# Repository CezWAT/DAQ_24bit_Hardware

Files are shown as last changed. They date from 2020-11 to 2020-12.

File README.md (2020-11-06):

# DAQ_24bit
Simple 4 channel 24bit USB DAQ
Uses ADS122U04 ADC and MCP2200 UART/GPIO - USB converter. No Dedicated uC.
4 Input channels with 4 ranges (+- 1V, 2V, 10V, 25V) and 2 current output channels.

Project for fun and curiosity with a purpose to make a simple yte precise USB DAQ without a dedicated controller requireig firmware. 

Forked to add an Eagle based pcb made by myself.

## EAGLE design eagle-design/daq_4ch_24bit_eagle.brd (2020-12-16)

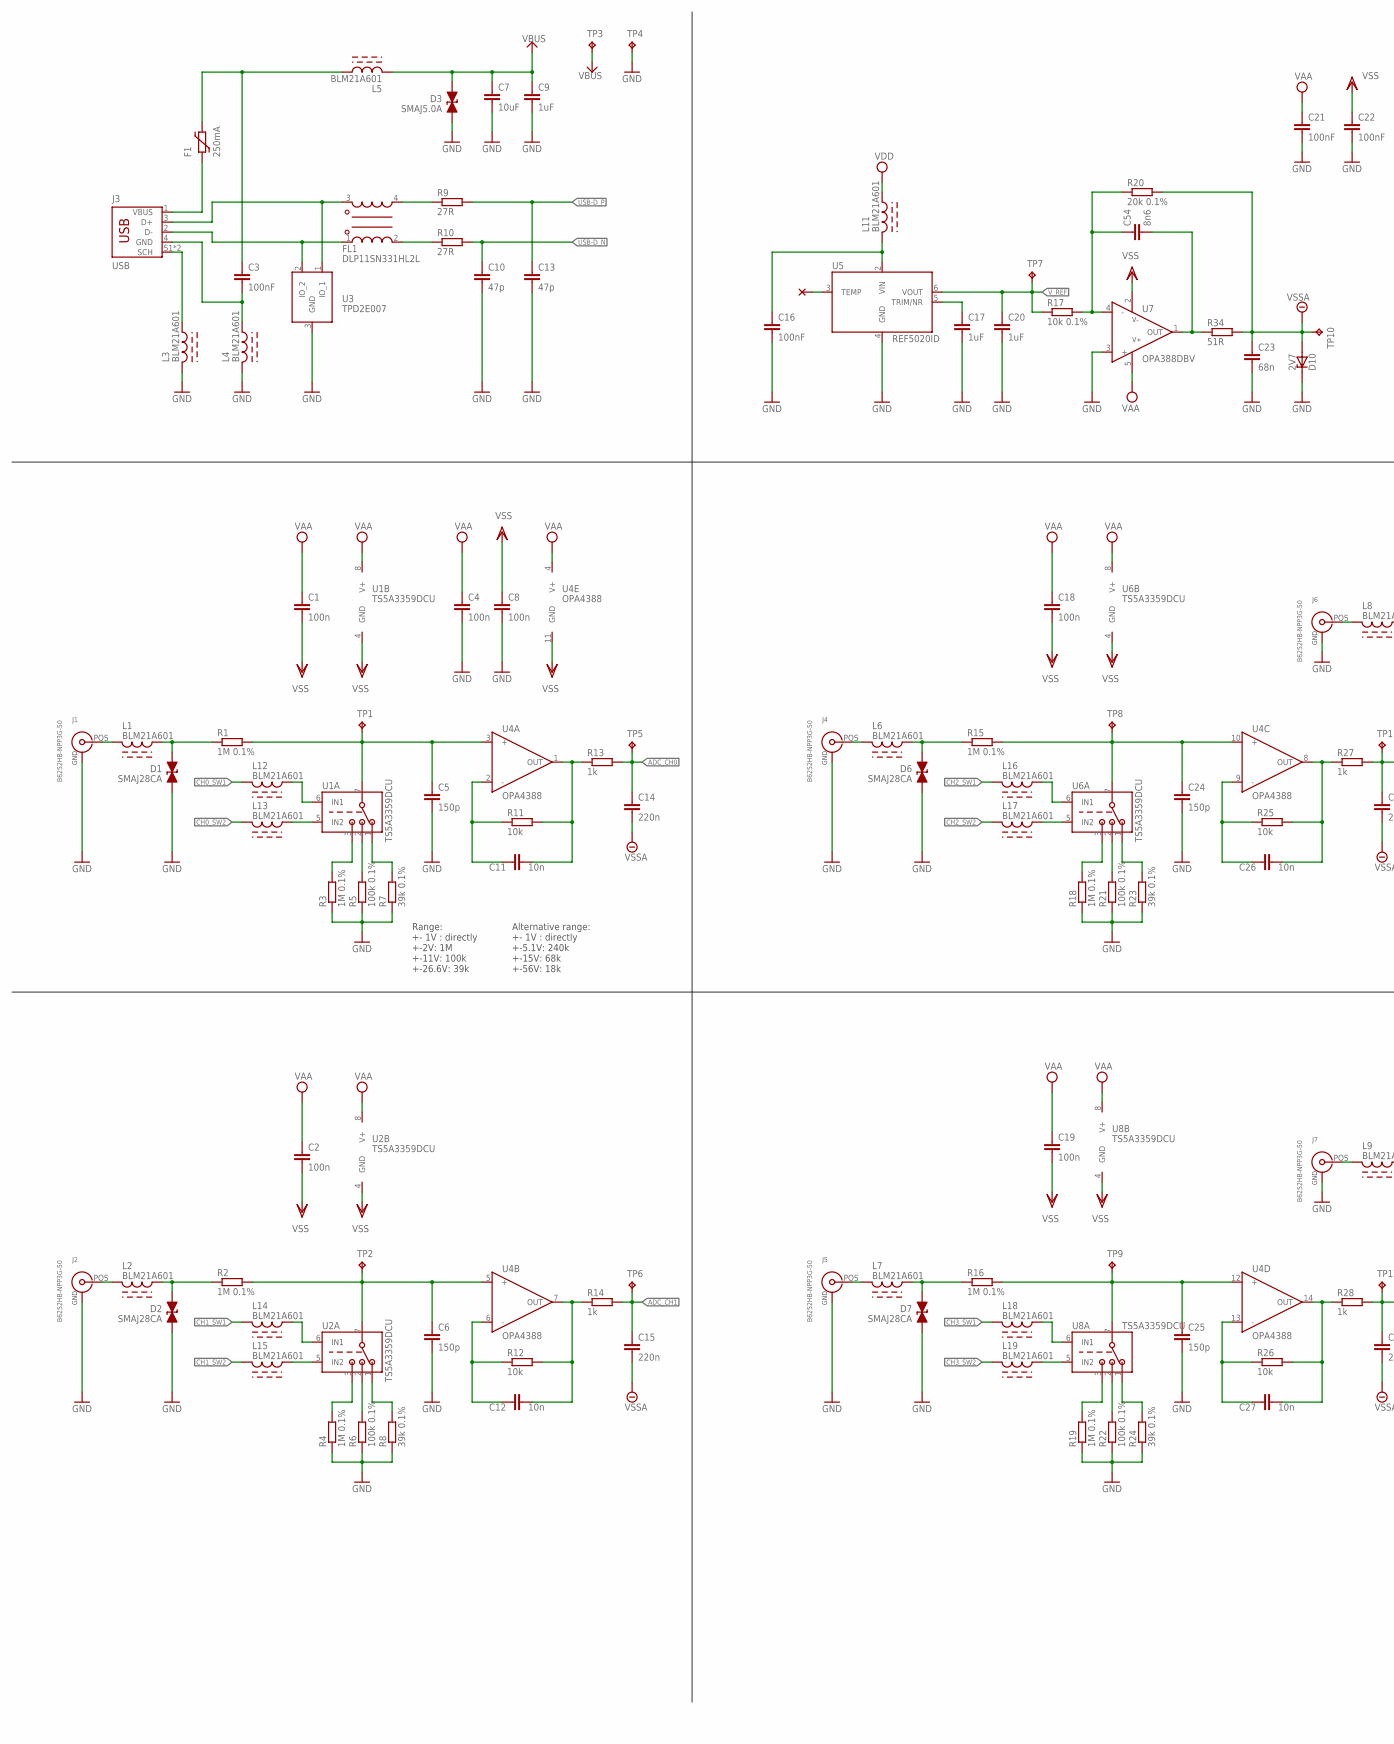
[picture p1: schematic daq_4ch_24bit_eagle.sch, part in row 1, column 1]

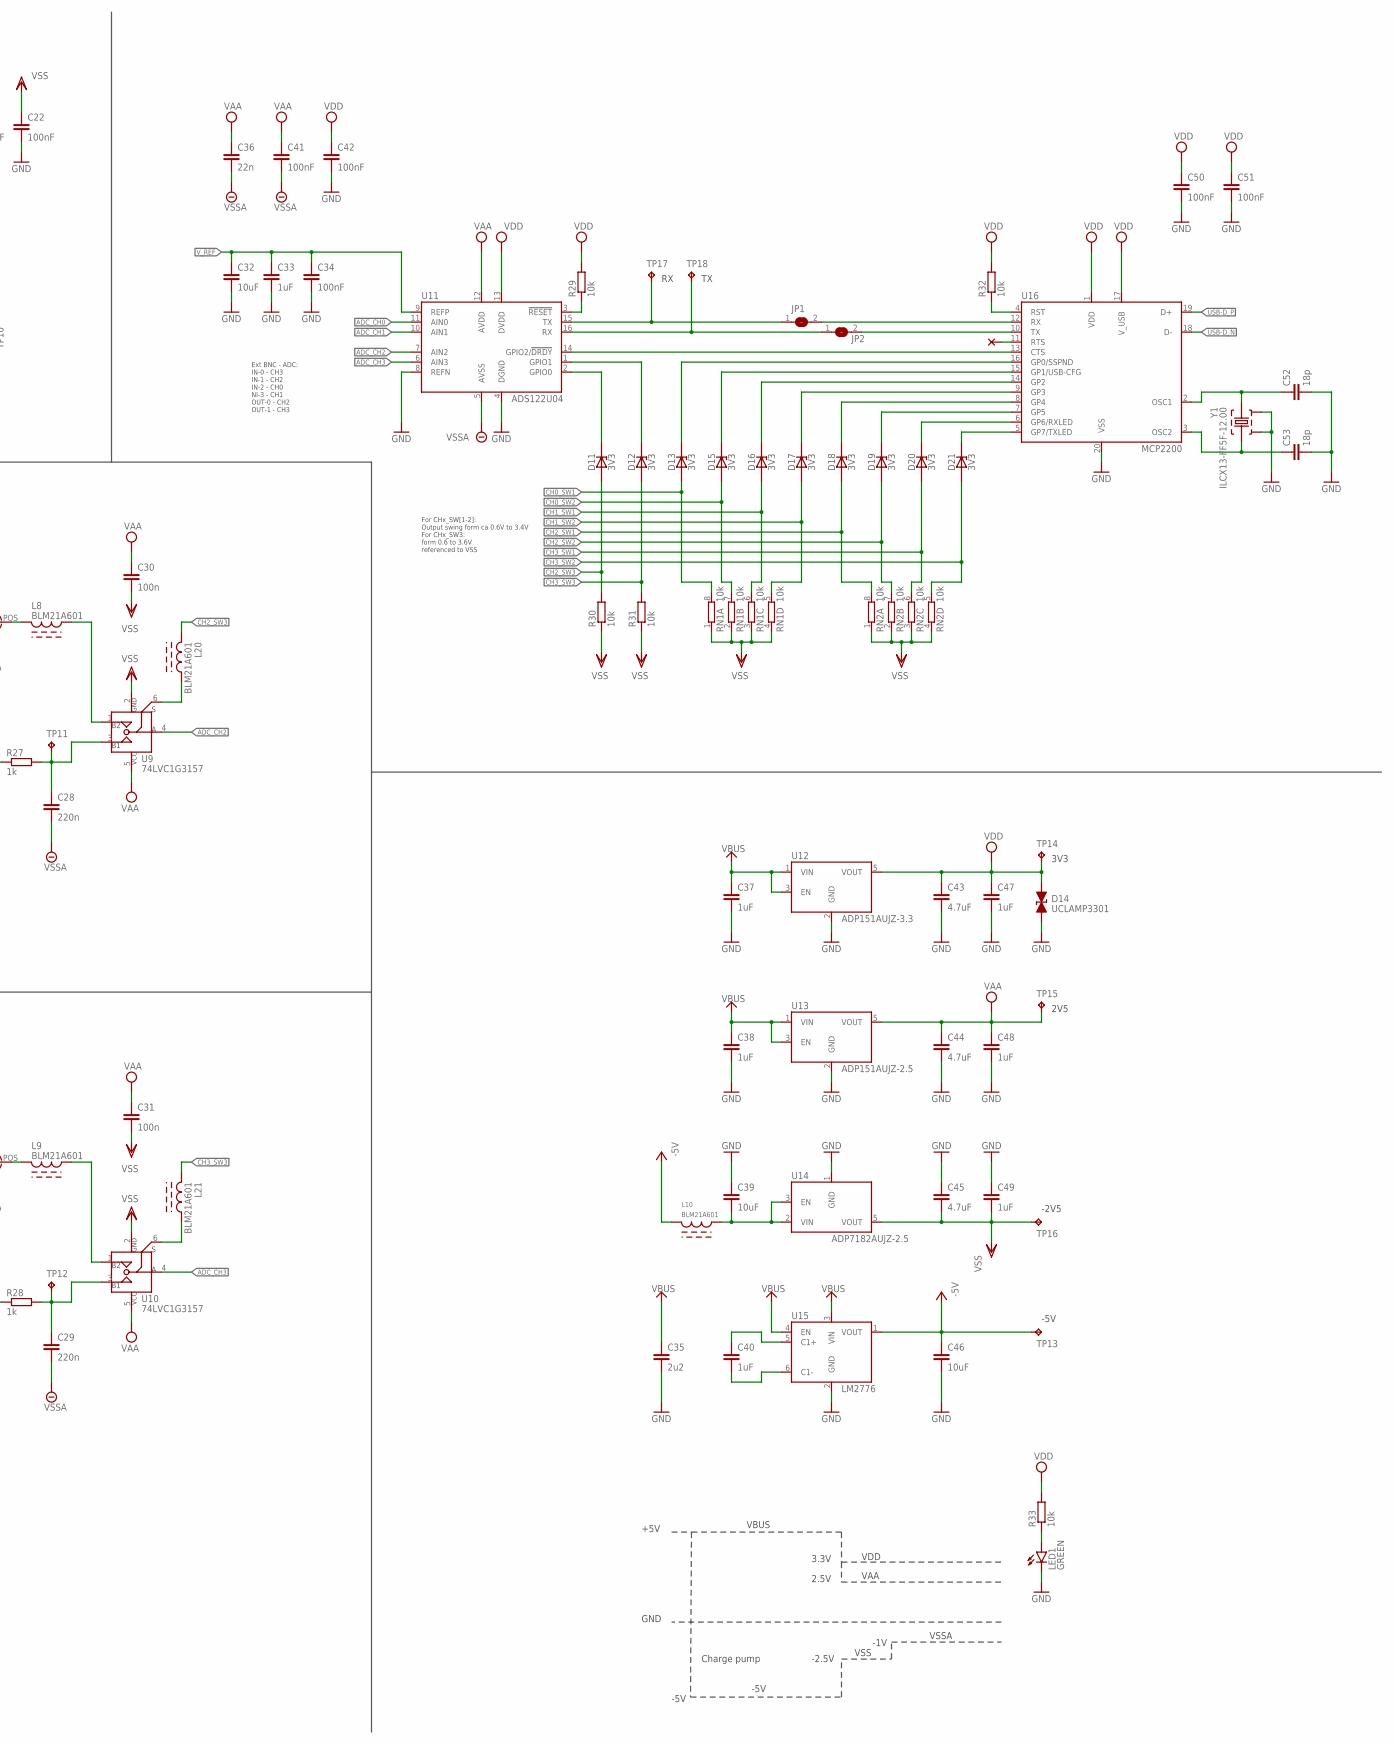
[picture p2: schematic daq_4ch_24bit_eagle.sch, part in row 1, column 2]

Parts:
C1, C2, C4, C8, C18, C19, C30, C31: 100n; C0603
C3, C16, C21, C22, C34, C41, C42, C50, C51: 100nF; C0603
C5, C6, C24, C25: 150p; C0603
C7, C32, C39, C46: 10uF; C0603
C9, C17, C20, C33, C37, C38, C40, C47, C48, C49: 1uF; C0603
C10, C13: 47p; C0603
C11, C12, C26, C27: 10n; C0603
C14, C15, C28, C29: 220n; C0603
C23: 68n; C0603
C35: 2u2; C0603
C36: 22n; C0603
C43, C44, C45: 4.7uF; C0603
C52, C53: 18p; C0603
C54: 8n6; C0603
D1, D2, D6, D7: SMAJ28CA; SMA(UNI)
D3: SMAJ5.0A; SMA(UNI)
D10: 2V7; SOD323
D11, D12, D13, D15, D16, D17, D18, D19, D20, D21: 3V3; SOD323
D14: UCLAMP3301; SOD323
F1: 250mA; 1812L
FL1: DLP11SN331HL2L
J1, J2, J4, J5, J6, J7: B6252HB-NPP3G-50
J3: USB; USB_B_THT
JP1, JP2: SJ
L1, L2, L3, L4, L5, L6, L7, L8, L9, L10, L11, L12, L13, L14, L15, L16, L17, L18, L19, L20, L21: BLM21A601; L0805
LED1: GREEN; LED5MM
R1, R2, R3, R4, R15, R16, R18, R19: 1M 0.1%; R0603
R5, R6, R21, R22: 100k 0.1%; R0603
R7, R8, R23, R24: 39k 0.1%; R0603
R9, R10: 27R; R0603
R11, R12, R25, R26, R29, R30, R31, R32, R33: 10k; R0603
R13, R14, R27, R28: 1k; R0603
R17: 10k 0.1%; R0603
R20: 20k 0.1%; R0603
R34: 51R; R0603
RN1, RN2: 10k; 0603-ARV
TP1, TP2, TP3, TP4, TP5, TP6, TP7, TP8, TP9, TP10, TP11, TP12, TP14: 3V3; B1,27
TP13: -5V; B1,27
TP15: 2V5; B1,27
TP16: -2V5; B1,27
TP17: RX; B1,27
TP18: TX; B1,27
U1, U2, U6, U8: TS5A3359DCU; DCU
U3: TPD2E007; SOT323
U4: OPA4388; SOIC14
U5: REF5020ID; SOIC8
U7: OPA388DBV; SOT23-5
U9, U10: 74LVC1G3157; SOT23-6
U11: ADS122U04; SSOP16
U12: ADP151AUJZ-3.3; SOT23-5
U13: ADP151AUJZ-2.5; SOT23-5
U14: ADP7182AUJZ-2.5; SOT23-5
U15: LM2776; SOT23-6
U16: MCP2200; SSOP20
Y1: ILCX13-FF5F-12.00; ILCX13

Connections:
-5V: C46.1, L10.1, TP13.TP, U15.1 (VOUT)
ADC_CH0: C14.1, R13.2, TP5.TP, U11.11 (AIN0)
ADC_CH1: C15.1, R14.2, TP6.TP, U11.10 (AIN1)
ADC_CH2: U9.4 (A), U11.7 (AIN2)
ADC_CH3: U10.4 (A), U11.6 (AIN3)
CH0_SW1: D13.A, L12.1, RN1.8 (2)
CH0_SW2: D15.A, L13.1, RN1.7 (2)
CH1_SW1: D16.A, L14.1, RN1.6 (2)
CH1_SW2: D17.A, L15.1, RN1.5 (2)
CH2_SW1: D18.A, L16.1, RN2.8 (2)
CH2_SW2: D19.A, L17.1, RN2.7 (2)
CH2_SW3: D11.A, L20.1, R30.2
CH3_SW1: D20.A, L18.1, RN2.6 (2)
CH3_SW2: D21.A, L19.1, RN2.5 (2)
CH3_SW3: D12.A, L21.1, R31.2
GND: C4.2, C5.2, C6.2, C7.2, C8.2, C9.2, C10.2, C13.2, C16.2, C17.2, C20.2, C21.2, C22.2, C23.2, C24.2, C25.2, C32.2, C33.2, C34.2, C35.2, C37.2, C38.2, C39.1, C42.2, C43.2, C44.2, C45.1, C46.2, C47.2, C48.2, C49.1, C50.2, C51.2, C52.2, C53.2, D1.2, D2.2, D3.2, D6.2, D7.2, D10.C, D14.C (2), J1.2 (GND), J1.3 (GND), J1.4 (GND), J2.2 (GND), J2.3 (GND), J2.4 (GND), J4.2 (GND), J4.3 (GND), J4.4 (GND), J5.2 (GND), J5.3 (GND), J5.4 (GND), J6.2 (GND), J6.3 (GND), J6.4 (GND), J7.2 (GND), J7.3 (GND), J7.4 (GND), L3.1, L4.1, LED1.K (C), R3.1, R4.1, R5.1, R6.1, R7.1, R8.1, R18.1, R19.1, R21.1, R22.1, R23.1, R24.1, TP4.TP, U3.3 (GND), U5.4 (GND), U7.3 (+), U11.4 (DGND), U11.8 (REFN), U12.2 (GND), U13.2 (GND), U14.1 (GND), U15.2 (GND), U16.20 (VSS), Y1.2, Y1.4
unnamed: C40.1, U15.5 (C1+)
unnamed: C40.2, U15.6 (C1-)
unnamed: C39.2, L10.2, U14.2 (VIN), U14.3 (EN)
unnamed: D21.C, U16.5 (GP7/TXLED)
unnamed: D20.C, U16.6 (GP6/RXLED)
unnamed: D19.C, U16.7 (GP5)
unnamed: D18.C, U16.8 (GP4)
unnamed: D17.C, U16.9 (GP3)
unnamed: D16.C, U16.14 (GP2)
unnamed: D15.C, U16.15 (GP1/USB-CFG)
unnamed: D13.C, U16.16 (GP0/SSPND)
unnamed: D11.C, U11.2 (GPIO0)
unnamed: D12.C, U11.1 (GPIO1)
unnamed: JP2.1, TP18.TP, U11.16 (RX)
unnamed: JP1.1, TP17.TP, U11.15 (TX)
unnamed: R32.1, U16.4 (RST)
unnamed: JP1.2, U16.12 (RX)
unnamed: JP2.2, U16.10 (TX)
unnamed: U11.14 (GPIO2/!DRDY), U16.13 (CTS)
unnamed: R29.1, U11.3 (!RESET)
unnamed: LED1.A, R33.1
unnamed: C3.1, F1.2, L5.2
unnamed: J3.S1 (SCH), J3.S2 (SCH), L3.2
unnamed: FL1.2, R10.1
unnamed: FL1.4, R9.1
unnamed: C16.1, L11.1, U5.2 (VIN)
unnamed: C17.1, U5.5 (TRIM/NR)
unnamed: C54.2, R34.1, U7.1 (OUT)
unnamed: C54.1, R17.2, R20.1, U7.4 (-)
unnamed: C52.1, U16.2 (OSC1), Y1.1
unnamed: C53.1, U16.3 (OSC2), Y1.3
unnamed: J1.POS, L1.1
unnamed: D1.1, L1.2, R1.1
unnamed: C11.2, R11.2, R13.1, U4.1 (OUT)
unnamed: R5.2, U1.2 (NO1)
unnamed: L13.2, U1.5 (IN2)
unnamed: L12.2, U1.6 (IN1)
unnamed: C5.1, R1.2, TP1.TP, U1.7 (COM), U4.3 (+)
unnamed: R7.2, U1.1 (NO0)
unnamed: R3.2, U1.3 (NO2)
unnamed: C11.1, R11.1, U4.2 (-)
unnamed: J4.POS, L6.1
unnamed: D6.1, L6.2, R15.1
unnamed: L17.2, U6.5 (IN2)
unnamed: L16.2, U6.6 (IN1)
unnamed: C24.1, R15.2, TP8.TP, U4.10 (+), U6.7 (COM)
unnamed: R21.2, U6.2 (NO1)
unnamed: R23.2, U6.1 (NO0)
unnamed: R18.2, U6.3 (NO2)
unnamed: C26.2, R25.2, R27.1, U4.8 (OUT)
unnamed: C26.1, R25.1, U4.9 (-)
unnamed: C28.1, R27.2, TP11.TP, U9.3 (B1)
unnamed: J6.POS, L8.1
unnamed: L8.2, U9.1 (B2)
unnamed: L20.2, U9.6 (S)
unnamed: J2.POS, L2.1
unnamed: D2.1, L2.2, R2.1
unnamed: L15.2, U2.5 (IN2)
unnamed: L14.2, U2.6 (IN1)
unnamed: C6.1, R2.2, TP2.TP, U2.7 (COM), U4.5 (+)
unnamed: R6.2, U2.2 (NO1)
unnamed: R8.2, U2.1 (NO0)
unnamed: R4.2, U2.3 (NO2)
unnamed: C12.2, R12.2, R14.1, U4.7 (OUT)
unnamed: C12.1, R12.1, U4.6 (-)
unnamed: J5.POS, L7.1
unnamed: D7.1, L7.2, R16.1
unnamed: L19.2, U8.5 (IN2)
unnamed: L18.2, U8.6 (IN1)
unnamed: C25.1, R16.2, TP9.TP, U4.12 (+), U8.7 (COM)
unnamed: R22.2, U8.2 (NO1)
unnamed: R24.2, U8.1 (NO0)
unnamed: R19.2, U8.3 (NO2)
unnamed: C27.2, R26.2, R28.1, U4.14 (OUT)
unnamed: C27.1, R26.1, U4.13 (-)
unnamed: C29.1, R28.2, TP12.TP, U10.3 (B1)
unnamed: J7.POS, L9.1
unnamed: L9.2, U10.1 (B2)
unnamed: L21.2, U10.6 (S)
USB-D_N: C10.1, R10.2, U16.18 (D-)
USB-D_P: C13.1, R9.2, U16.19 (D+)
USBD_N: FL1.1, J3.2 (D-), U3.2 (IO_2)
USBD_P: FL1.3, J3.3 (D+), U3.1 (IO_1)
USBGND: C3.2, J3.4 (GND), L4.2
VAA: C1.1, C2.1, C4.1, C18.1, C19.1, C21.1, C30.1, C31.1, C36.1, C41.1, C44.1, C48.1, TP15.TP, U1.8 (V+), U2.8 (V+), U4.4 (V+), U6.8 (V+), U7.5 (V+), U8.8 (V+), U9.5 (VCC), U10.5 (VCC), U11.12 (AVDD), U13.5 (VOUT)
VBUS: C7.1, C9.1, C35.1, C37.1, C38.1, D3.1, L5.1, TP3.TP, U12.1 (VIN), U12.3 (EN), U13.1 (VIN), U13.3 (EN), U15.3 (VIN), U15.4 (EN)
VDD: C42.1, C43.1, C47.1, C50.1, C51.1, D14.A (1), L11.2, R29.2, R32.2, R33.2, TP14.TP, U11.13 (DVDD), U12.5 (VOUT), U16.1 (VDD), U16.17 (V_USB)
VSS: C1.2, C2.2, C8.1, C18.2, C19.2, C22.1, C30.2, C31.2, C45.2, C49.2, R30.1, R31.1, RN1.1, RN1.2 (1), RN1.3 (1), RN1.4 (1), RN2.1, RN2.2 (1), RN2.3 (1), RN2.4 (1), TP16.TP, U1.4 (GND), U2.4 (GND), U4.11 (GND), U6.4 (GND), U7.2 (GND), U8.4 (GND), U9.2 (GND), U10.2 (GND), U14.5 (VOUT)
VSSA: C14.2, C15.2, C23.1, C28.2, C29.2, C36.2, C41.2, D10.A, R20.2, R34.2, TP10.TP, U11.5 (AVSS)
VUSB: F1.1, J3.1 (VBUS)
V_REF: C20.1, C32.1, C33.1, C34.1, R17.1, TP7.TP, U5.6 (VOUT), U11.9 (REFP)

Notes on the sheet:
For CHx_SW[1-2]: Output swing form ca 0.6V to 3.4V For CHx_SW3: form 0.6 to 3.6V referenced to VSS
Ext BNC - ADC: IN-0 - CH3 IN-1 - CH2 IN-2 - CH0 NI-3 - CH1 OUT-0 - CH2 OUT-1 - CH3
3V3
2V5
-2V5
-5V
GND
+5V
VBUS
3.3V
2.5V
VDD
VAA
Charge pump
-2.5V
VSS
-1V
VSSA
Alternative range: +- 1V : directly +-5.1V: 240k +-15V: 68k +-56V: 18k
Range: +- 1V : directly +-2V: 1M +-11V: 100k +-26.6V: 39k

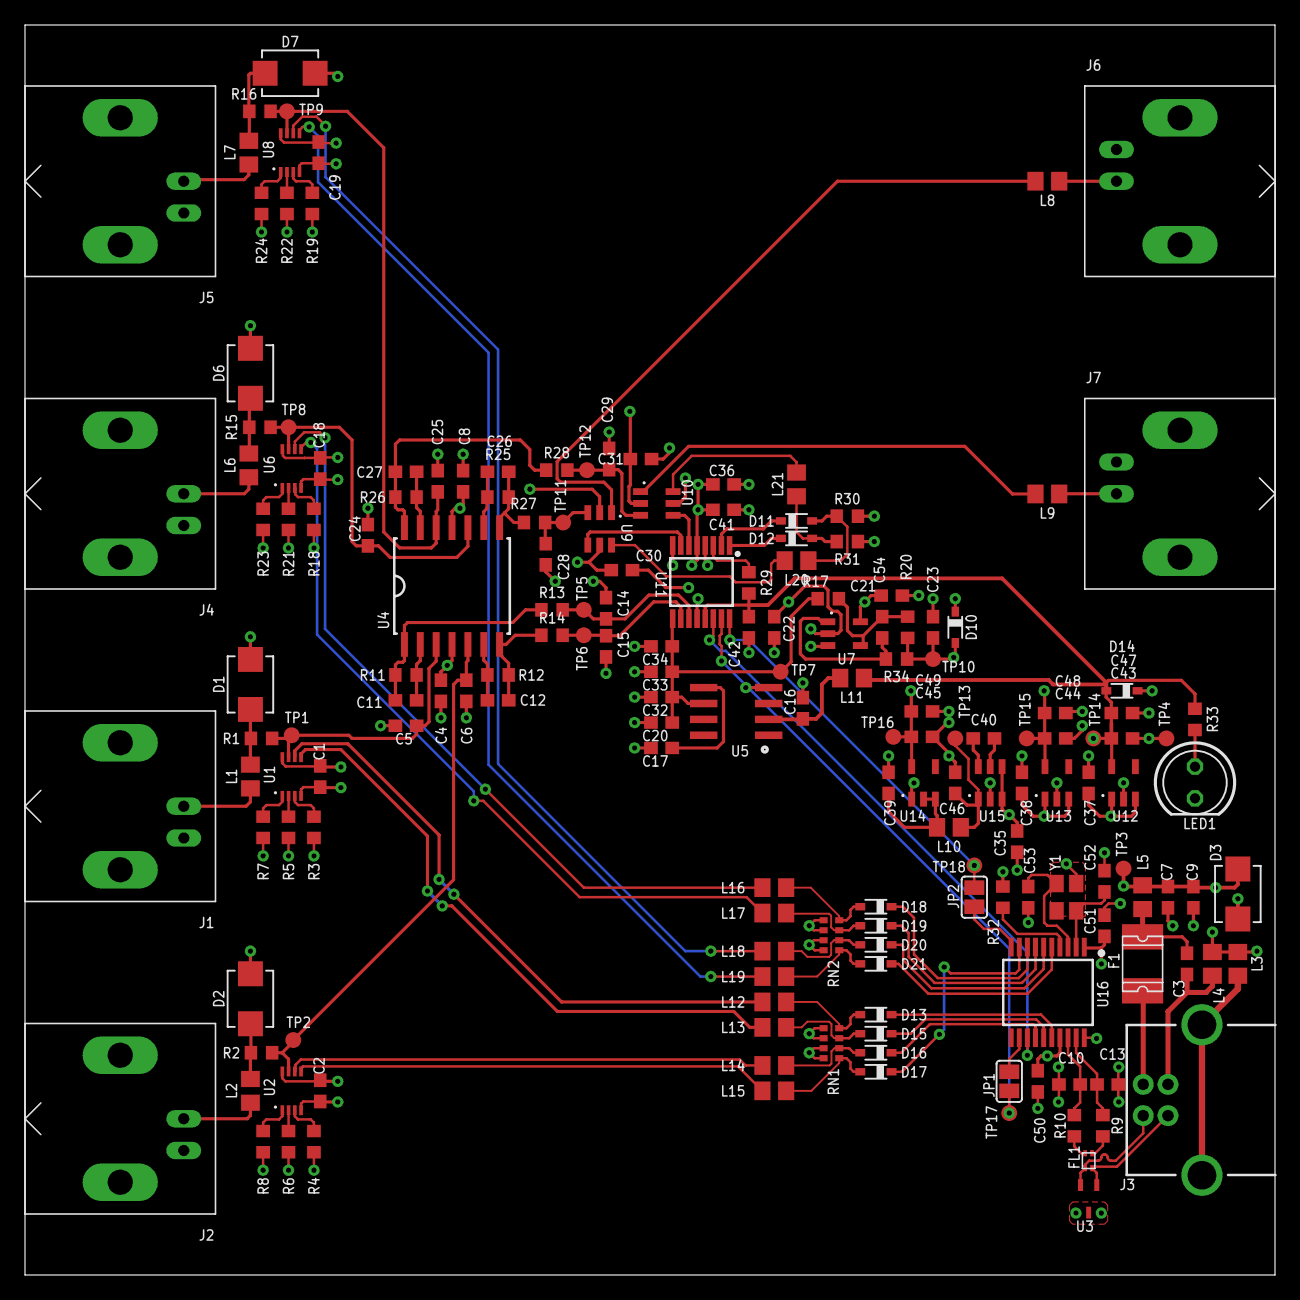
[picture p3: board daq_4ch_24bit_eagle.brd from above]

Board: 4 copper layers, 100.0 x 100.0 mm, 175 parts (0 on the bottom side), 107 nets.

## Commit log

2020-11-27 Add schematic & library in eagle, generated pcb from sch
    [daq_4ch_24bit_eagle.brd, daq_4ch_24bit_eagle.sch]
2020-12-12 Fixes to schematic and library, begin placement and routing
    [daq_4ch_24bit_eagle.brd, daq_4ch_24bit_eagle.sch]
2020-12-16 Fix on schematic, placement and routing done, needs impendance calculation, first iteration - could be improved
    [daq_4ch_24bit_eagle.brd, daq_4ch_24bit_eagle.sch]
